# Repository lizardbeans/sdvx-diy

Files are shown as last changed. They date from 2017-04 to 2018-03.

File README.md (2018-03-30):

# SDVX Controller (DIY)

<div style='float: center'>
  
</div>

<hr>

Check [consandstuff.github.io/sound-voltex](http://consandstuff.github.io/rhythmcons/sound-voltex/sdvx-normal/) for full instructions.

CODE INSTRUCTIONS:

* Download and install ARDUINO IDE v1.8
https://www.arduino.cc/en/Main/OldSoftwareReleases#previous 

* Download and install Teensyduino
https://www.pjrc.com/teensy/td_download.html

* Add these lines to the C:\Program Files (x86)\Arduino\hardware\teensy\avr boards.txt file and save. 

teensy31.menu.usb.sdvx=SDVX controller

teensy31.menu.usb.sdvx.build.usbtype=USB_ARCADE

teensy31.menu.usb.sdvx.fake_serial=teensy_gateway

* Then add the 4 usb_arcade and usb_desc inside yout core/teensy3 folder and overwirte existing files.

*Alternatively download the whole set of folders and paste into Program Files.

* Open teensyduino and connect your PCB to the PC using a USB cable
* In Tools/USB Type choose SDVX Controller
* Open a blank Arduino IDE file (FIle - New) and click Verify to open the Teensyduino UI
* Hit the "Open HEX file" button and choose the file
* Click the hardware reset button on the Teensy PCB and it will upload.

Then you're done!

For the Leonardo CODE you'll need only Arduino IDE. Set the Arduino for a Leonardo and choose the right COM port.

<hr>

## Part List / Hardware

Check out the parts used on my website
You can find links here: http://consandstuff.github.io/rhythmcons/sound-voltex/sdvx-normal/

Skills needed:
* Wood cutting
* Soldering
* Drilling
* Sanding

## Part List / Building Materials

**Main box**
Made out of 5mm MDF planks. You have to make the box 3mm narrower on each side to mount the 3mm black acrylic.

**Side plates**
Made out of black 3mm acrylic. See CAD file.

**Top plate**
Made out of laser cut clear 5mm acrylic. See CAD file.

**Other**
20xM5 bolts, 4xM6 bolts, 4xmagnetic locks

<hr>

**PIN DIAGRAM (teensy only)**
<table><thead>
<tr>
<th>Button</th>
<th style="text-align: center">Pin #</th>
<th style="text-align: center">Button #</th>
<th style="text-align: center">LED Pin #</th>
</tr>
</thead><tbody>
<tr>
<td>Start</td>
<td style="text-align: center">4</td>
<td style="text-align: center">Button 1</td>
<td style="text-align: center">-</td>
</tr>
<tr>
<td>BT-A</td>
<td style="text-align: center">5</td>
<td style="text-align: center">Button 2</td>
<td style="text-align: center">-</td>
</tr>
<tr>
<td>FX-L</td>
<td style="text-align: center">6</td>
<td style="text-align: center">Button 3</td>
<td style="text-align: center">-</td>
</tr>
<tr>
<td>BT-B</td>
<td style="text-align: center">7</td>
<td style="text-align: center">Button 4</td>
<td style="text-align: center">-</td>
</tr>
<tr>
<td>BT-C</td>
<td style="text-align: center">8</td>
<td style="text-align: center">Button 5</td>
<td style="text-align: center">-</td>
</tr>
<tr>
<td>FX-R</td>
<td style="text-align: center">9</td>
<td style="text-align: center">Button 6</td>
<td style="text-align: center">-</td>
</tr>
<tr>
<td>BT-D</td>
<td style="text-align: center">10</td>
<td style="text-align: center">Button 7</td>
<td style="text-align: center">-</td>
</tr>
</tbody></table>

<table><thead>
<tr>
<th>ENCODERS</th>
<th style="text-align: center">DATA 1</th>
<th style="text-align: center">DATA 2</th>
</tr>
</thead><tbody>
<tr>
<td>Left knob (VOL-L)
<td style="text-align: center">0</td>
<td style="text-align: center">1</td>
</tr>
<tr>
<td>Right knob (VOL-R)
<td style="text-align: center">2</td>
<td style="text-align: center">3</td>
</tr>
</tbody></table>

**Also you have to connect the encoders to the VUSB pin to get the 5v input**

<hr>

**PIN LAYOUT (LEONARDO ARDUINO)**

<table><thead>
<tr>
<th>Button</th>
<th style="text-align: center">Pin #</th>
<th style="text-align: center">Button #</th>
<th style="text-align: center">LED Pin #</th>
</tr>
</thead><tbody>
<tr>
<td>Start</td>
<td style="text-align: center">13</td>
<td style="text-align: center">Button 1</td>
<td style="text-align: center">6</td>
</tr>
<tr>
<td>BT-A</td>
<td style="text-align: center">A0</td>
<td style="text-align: center">Button 2</td>
<td style="text-align: center">7</td>
</tr>
<tr>
<td>FX-L</td>
<td style="text-align: center">A1</td>
<td style="text-align: center">Button 3</td>
<td style="text-align: center">8</td>
</tr>
<tr>
<td>BT-B</td>
<td style="text-align: center">A2</td>
<td style="text-align: center">Button 4</td>
<td style="text-align: center">9</td>
</tr>
<tr>
<td>BT-C</td>
<td style="text-align: center">A3</td>
<td style="text-align: center">Button 5</td>
<td style="text-align: center">10</td>
</tr>
<tr>
<td>FX-R</td>
<td style="text-align: center">A4</td>
<td style="text-align: center">Button 6</td>
<td style="text-align: center">11</td>
</tr>
<tr>
<td>BT-D</td>
<td style="text-align: center">A5</td>
<td style="text-align: center">Button 7</td>
<td style="text-align: center">12</td>
</tr>
</tbody></table>

<table><thead>
<tr>
<th>ENCODERS</th>
<th style="text-align: center">DATA 1</th>
<th style="text-align: center">DATA 2</th>
</tr>
</thead><tbody>
<tr>
<td>Left knob (VOL-L)
<td style="text-align: center">0</td>
<td style="text-align: center">1</td>
</tr>
<tr>
<td>Right knob (VOL-R)
<td style="text-align: center">2</td>
<td style="text-align: center">3</td>
</tr>
</tbody></table>

>**Also you have to connect the encoders to the 5V pin for the 5v input**

<hr>

## Assembly / Building the controller

**Buttons**
Assembly every button in its place on the acrylic board. Use the plastic nut to keep them in place.
After that put the white plastic center in the button inserting it rotates 15° pushing and then locking it rotating it 15° back.
Don't forget to add your printed vynil bellow the clear acrylic before inserting the buttons.

**Encoders**
Mount the encoders using 3 small screws.

**Crimp Connectors**
Use crimp connectors in each wire of the 7 molex wires your gonna use. You should en up with 7 wires, each with 4 crimp connectors (1 LED, 1 DATA and 2 GROUND), and also 2 other wires for the encoders (1 DATA A, 1 DATA B, 1 5v input and 1 GROUND). 

**Perfboard**
Following this drawing (drawing pending) solder each male molex connector in the perfboard. Then using PCB wires solder each molex pin with another molex pin (For the DATA and LED pins) and solder all the grounds in a single line.

**Teensy**
Solder each corresponding molex wire to each hole in the PCB. You should end up with 3 6-pin wires.

Mount everything toghether connecting each molex wire to the perfboard and to the buttons.

>If a button doesn't work, try checking the solder to see if its connected properly. Also check the ground connections.

<hr>

## Gallery

[Step by step gallery](http://imgur.com/a/uVgB2)

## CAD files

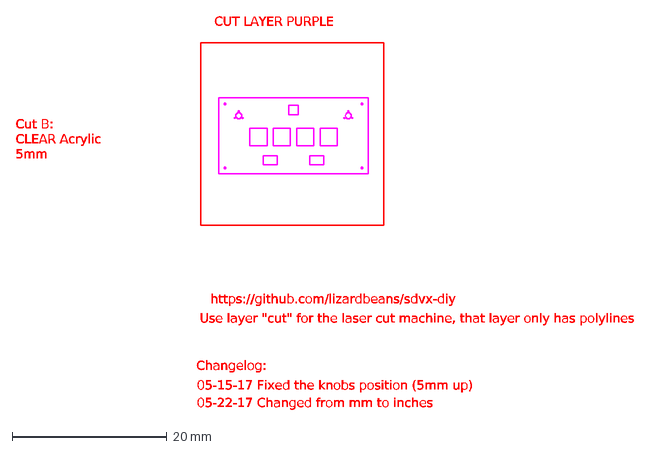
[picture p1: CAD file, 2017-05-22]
cad/Main Plate [inches] (AutoCAD 2010).dxf
Cut B:
CLEAR Acrylic
5mm
CUT LAYER PURPLE
https://github.com/lizardbeans/sdvx-diy
Use layer "cut" for the laser cut machine, that layer only has polylines
05-15-17 Fixed the knobs position (5mm up)
Changelog:
05-22-17 Changed from mm to inches

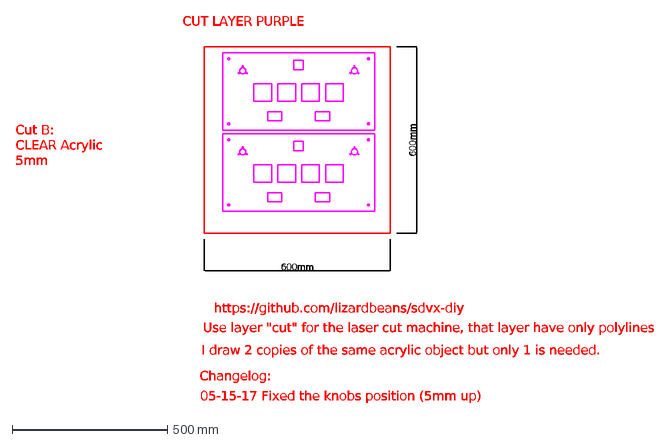
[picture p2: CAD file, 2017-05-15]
cad/Main Plate 600x600x5mm.dxf
Cut B:
CLEAR Acrylic
5mm
CUT LAYER PURPLE
600mm
https://github.com/lizardbeans/sdvx-diy
Use layer "cut" for the laser cut machine, that layer have only polylines
I draw 2 copies of the same acrylic object but only 1 is needed.
05-15-17 Fixed the knobs position (5mm up)
Changelog:

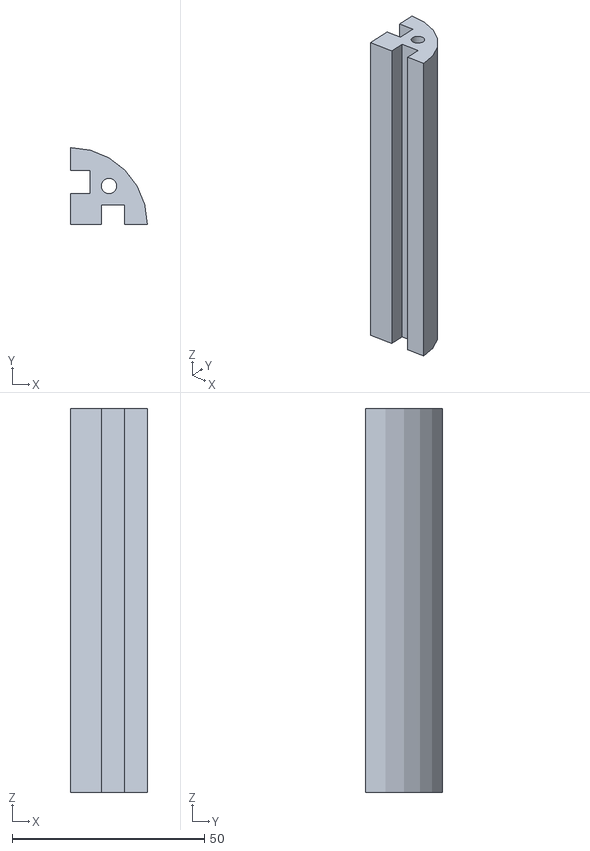
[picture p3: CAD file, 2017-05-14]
code Leonardo/skp/edge.stl
20.0 x 20.0 x 100.0

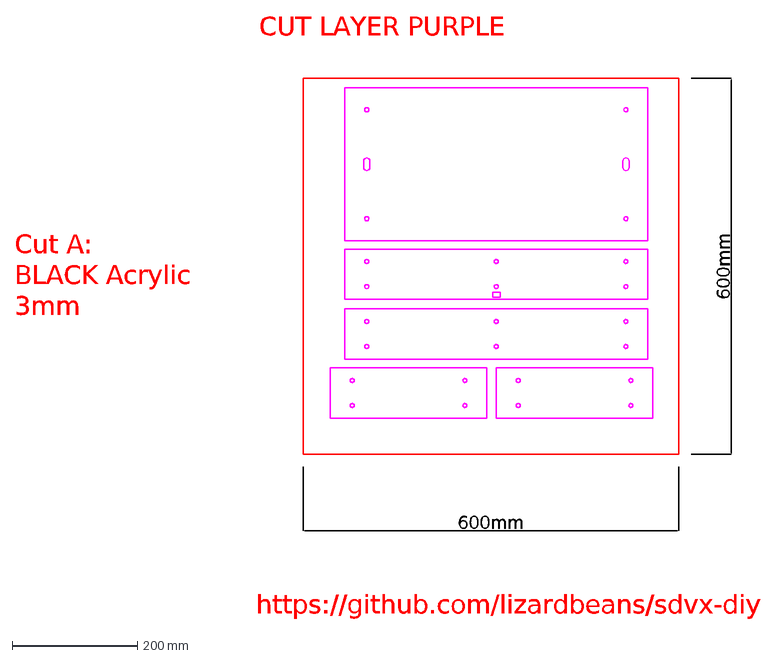
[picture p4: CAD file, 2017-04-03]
cad/Body 600x600x3mm.dxf
Cut A:
BLACK Acrylic
3mm
CUT LAYER PURPLE
600mm
https://github.com/lizardbeans/sdvx-diy

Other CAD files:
cad/Main Plate 600x600x5mm (AutoCAD 2010).dwg
cad/Main Plate 600x600x5mm (AutoCAD 2013).dwg
cad/Body 600x600x3mm (AutoCAD 2013).dwg
cad/Body 600x600x3mm (AutoCAD 2010).dwg
cad/Main Plate [inches] (AutoCAD 2010).dwg
code Leonardo/skp/edge.skp

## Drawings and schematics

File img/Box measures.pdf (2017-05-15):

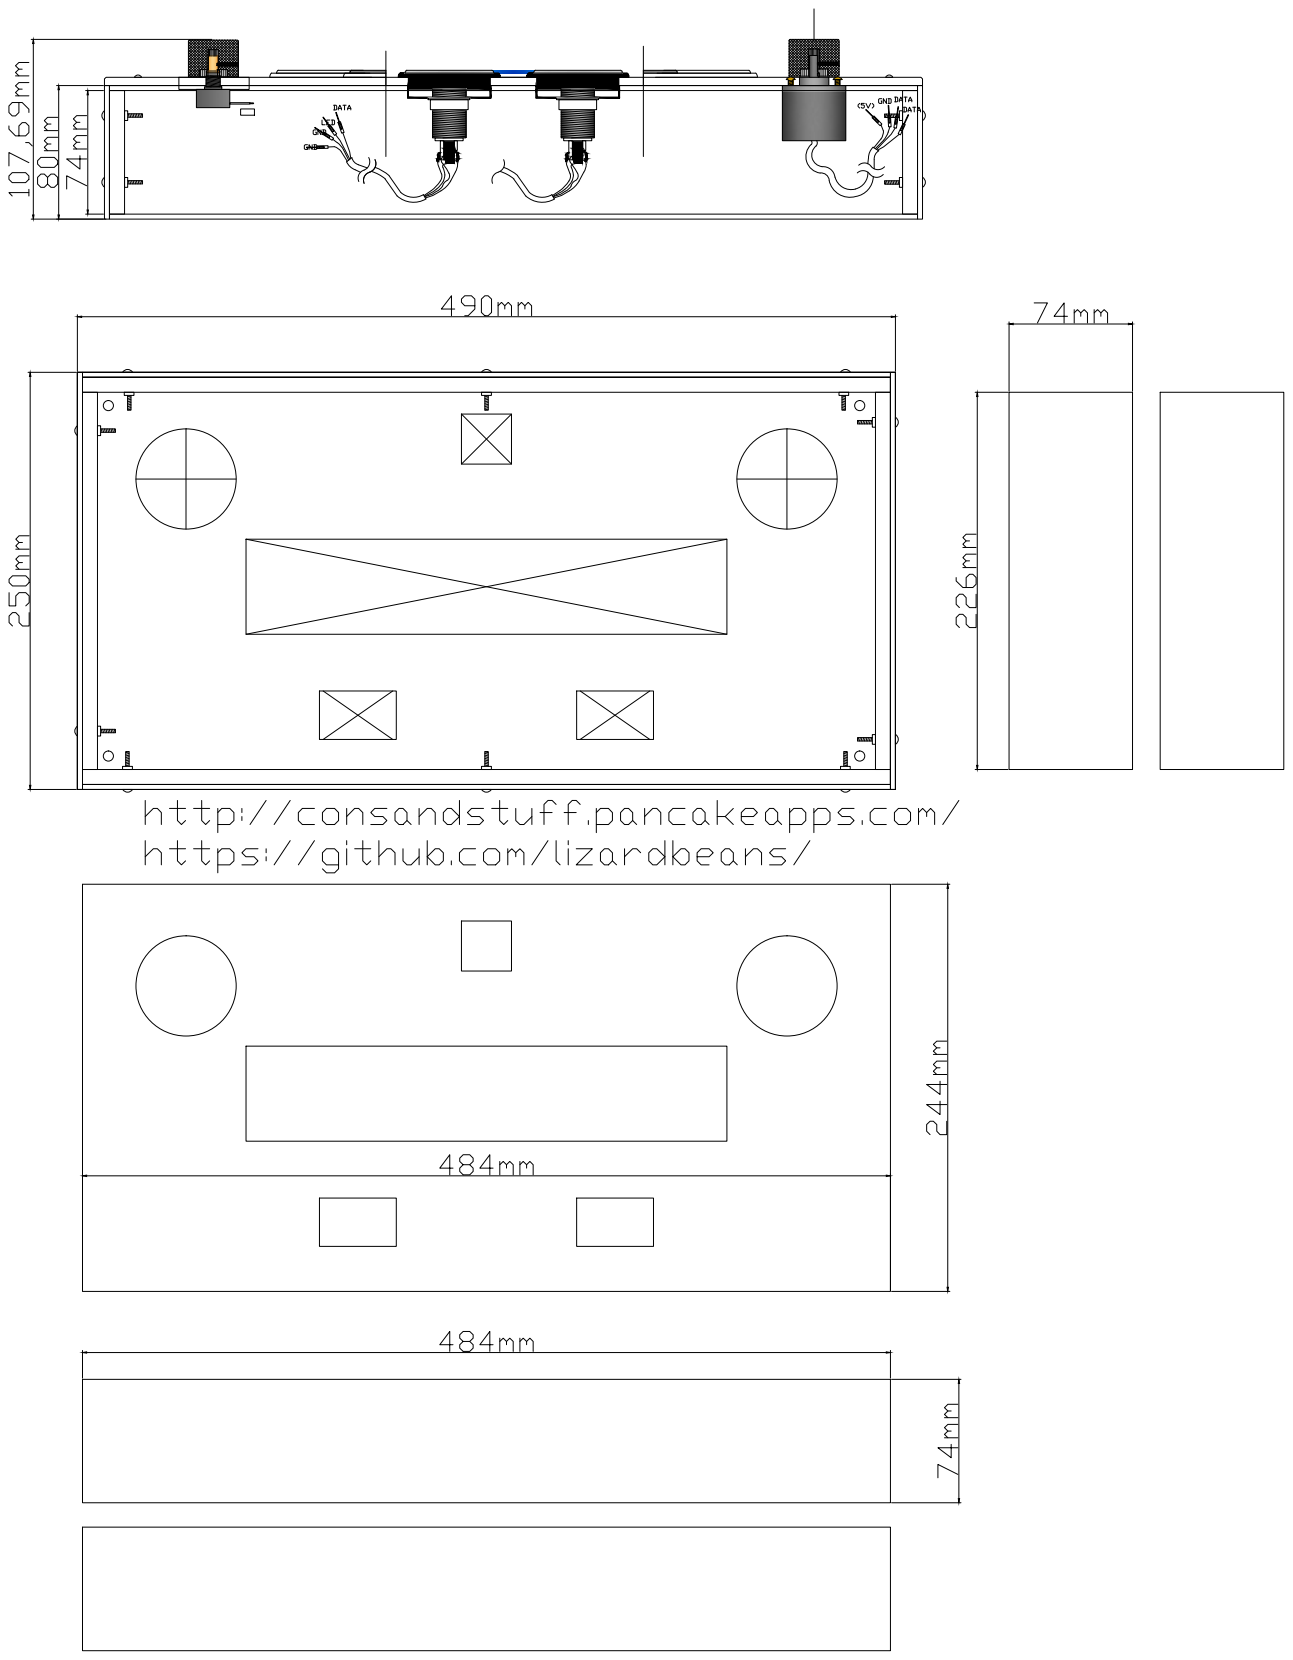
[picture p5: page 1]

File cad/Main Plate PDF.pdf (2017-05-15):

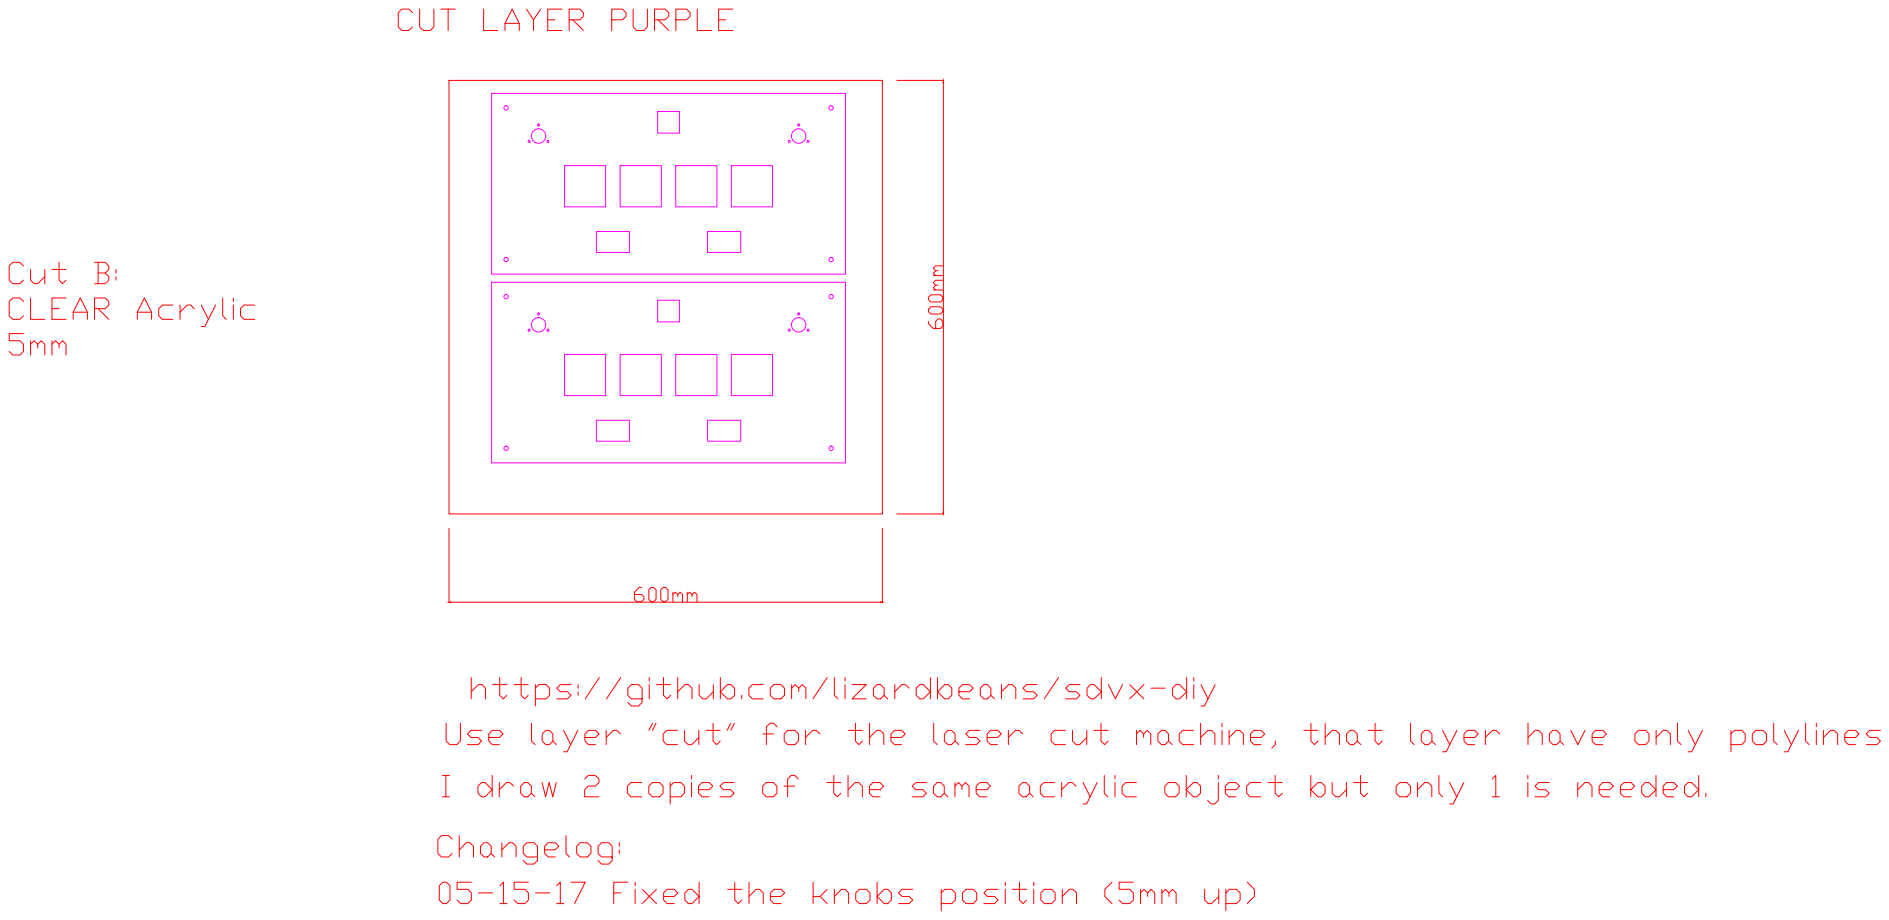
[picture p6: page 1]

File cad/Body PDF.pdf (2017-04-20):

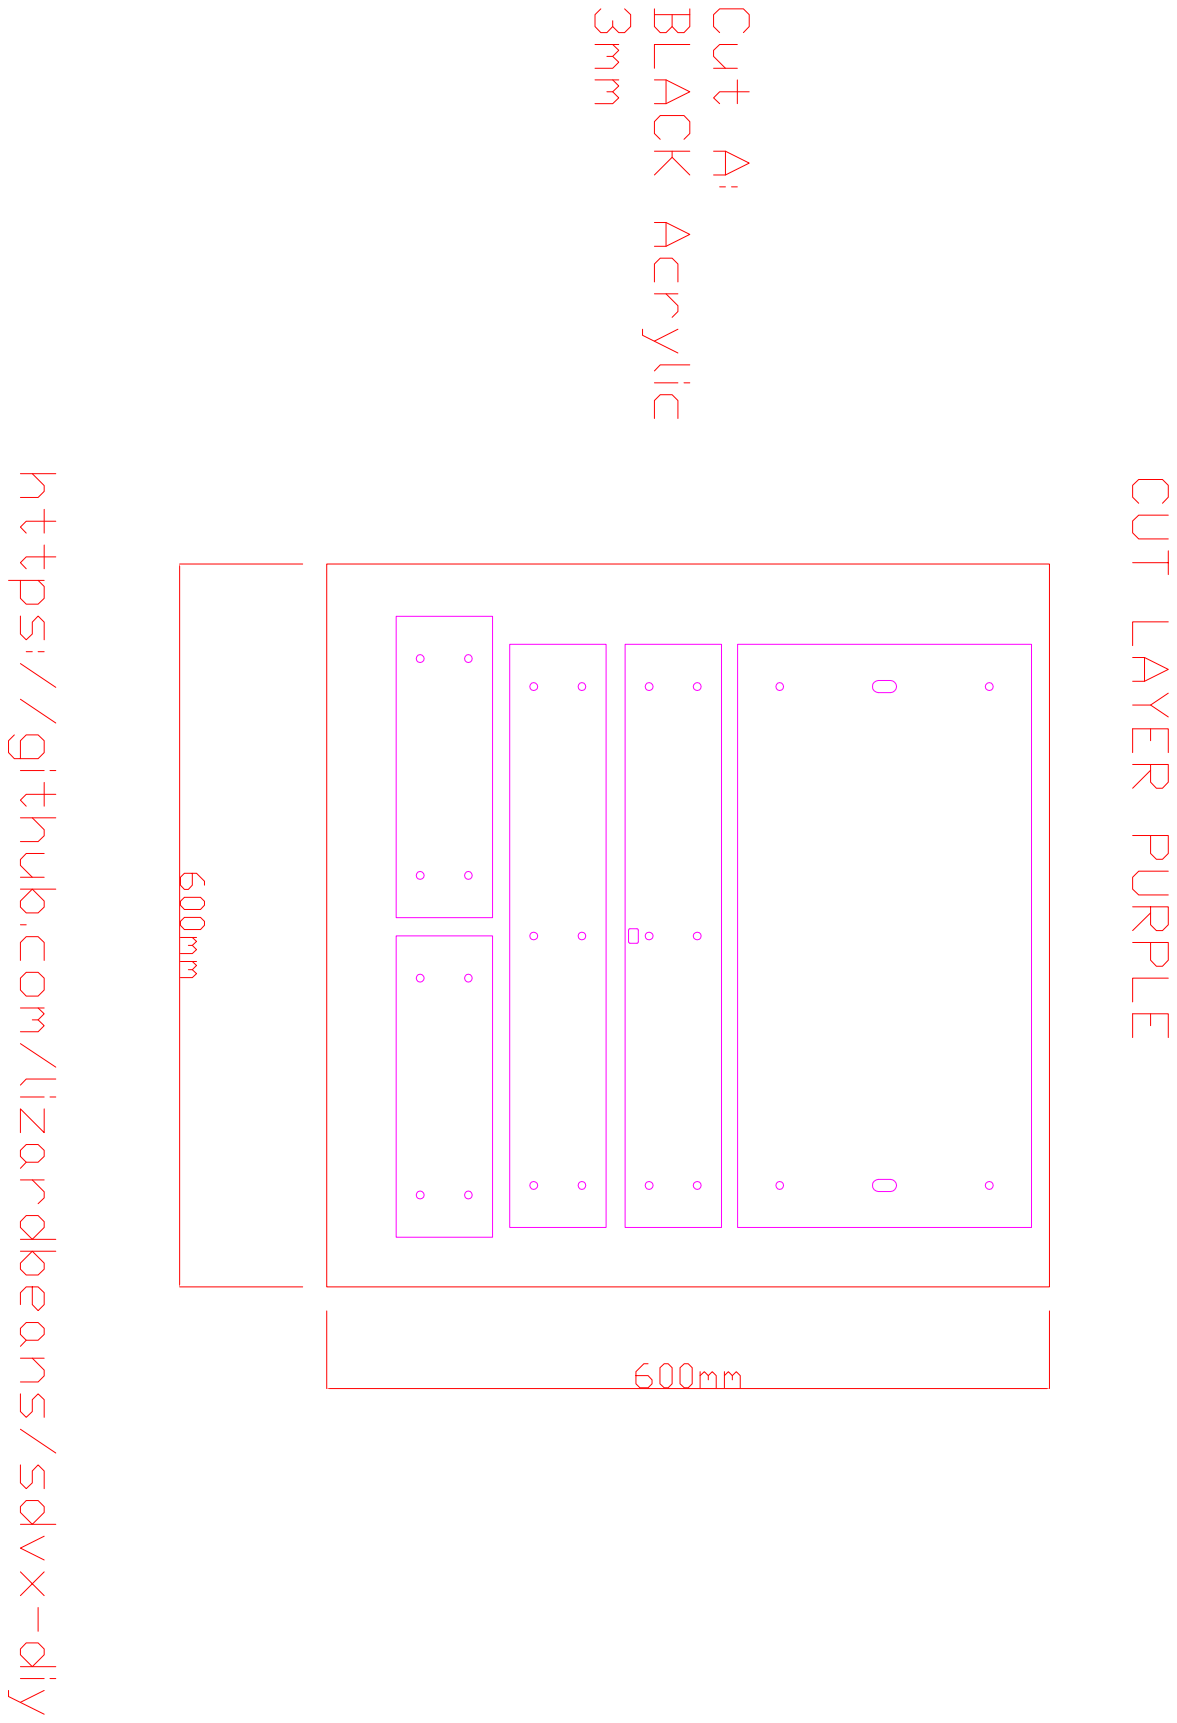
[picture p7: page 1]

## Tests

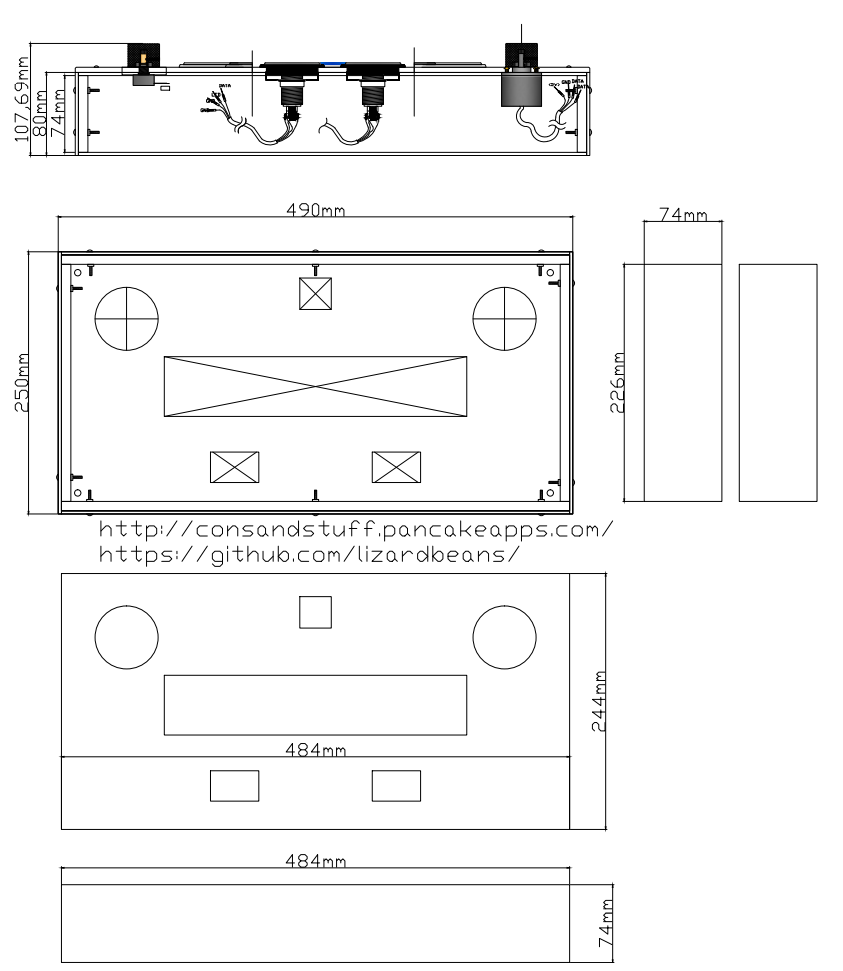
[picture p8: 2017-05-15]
img/Box Measures.png

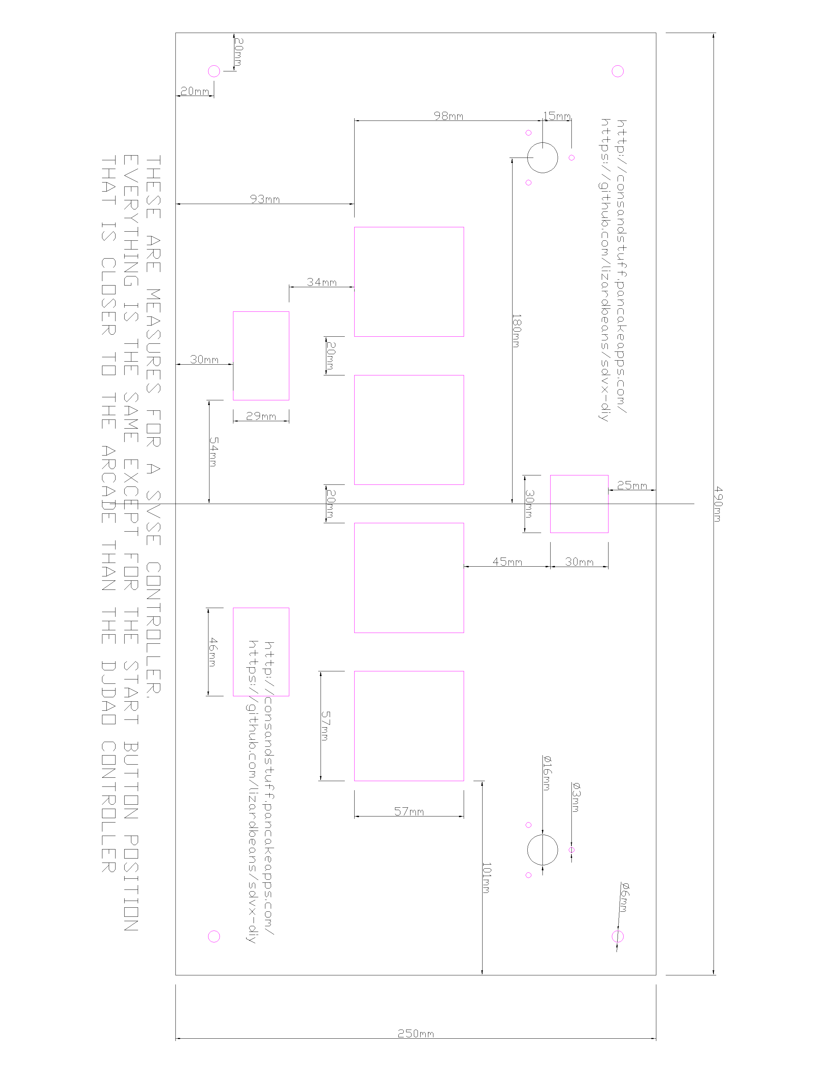
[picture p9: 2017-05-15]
img/SDVX measures.png

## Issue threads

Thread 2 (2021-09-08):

Encoders not working

MichaelOdet, 2021-09-08:
Hi,
Encoders not working. I use Arduino Leonardo.
When I test encoder with Windows Gaming Controller settings, buttons are OK. But nothing happen with encoders.

Just when I plug/unplug the +5V of left encoder, the X/Y axis increment of +1

Best regards.

michaelbutler, 2023-07-14:
@Mik027 did you ever figure it out?

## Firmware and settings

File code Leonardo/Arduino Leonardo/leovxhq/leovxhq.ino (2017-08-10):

#include "iivx_leo.h"
iivxReport_t report; 

#define REPORT_DELAY 2000
// Number of microseconds between HID reports
// 2000 = 500hz

#define ENC_L_A 0
#define ENC_L_B 1
#define ENC_L_B_ADDR 3
#define ENC_R_A 2
#define ENC_R_B 3
#define ENC_R_B_ADDR 0
#define ENCODER_SENSITIVITY (double) 2.34375
#define ENCODER_PORT PIND
// encoder sensitivity = number of positions per rotation (600/256) / number of positions for HID report (256)
/*
 * connect encoders
 * VOL-L to pins 0 and 1
 * VOL-R to pins 2 and 3
 */

int tmp;
uint8_t buttonCount = 7;
uint8_t lightMode = 0;
// 0 = reactive lighting, 1 = HID lighting
uint8_t ledPins[] = {6,7,8,9,10,11,12};
uint8_t buttonPins[] = {13,18,19,20,21,22,23};
uint8_t sysPin = 5;
uint8_t reactiveLightPin = 21;
uint8_t hidLightPin = 22;
uint8_t sysInputPins[] = {13,18,19,20};
int32_t encL=0, encR=0;
/* current pin layout
 *  pins 6 to 12 = LED 1 to 7
 *    connect pin to + termnial of LED
 *    connect ground to resistor and then - terminal of LED
 *  pins 13, A0 to A5 = Button input 1 to 7
 *    connect button pin to ground to trigger button press
 *  pins 5 = system pin
 *    connect system pin to ground with a small button
 *      press together with other buttons to change lighting scheme
 *    system button + button 1 = reactive lighting
 *    system button + button 3 = HID lighting
 */
 

void doEncL(){
  if((ENCODER_PORT >> ENC_L_B_ADDR)&1){
    encL++;
  } else {
    encL--;
  }
}

void doEncR(){
  if((ENCODER_PORT >> ENC_R_B_ADDR)&1){
    encR++;
  } else {
    encR--;
  }
}

void lights(uint8_t lightDesc){
  for(int i=0;i<buttonCount;i++){
     if((lightDesc>>i)&1){
         digitalWrite(ledPins[i],HIGH);
     } else {
         digitalWrite(ledPins[i],LOW);
     }
  }
}

void setup() {
  delay(1000);
  // Setup I/O for pins
  for(int i=0;i<buttonCount;i++){
    pinMode(buttonPins[i],INPUT_PULLUP);
    pinMode(ledPins[i],OUTPUT);
  }
  pinMode(sysPin,INPUT_PULLUP);
  //setup interrupts
  pinMode(ENC_L_A,INPUT_PULLUP);
  pinMode(ENC_L_B,INPUT_PULLUP);
  pinMode(ENC_R_A,INPUT_PULLUP);
  pinMode(ENC_R_B,INPUT_PULLUP);
  attachInterrupt(digitalPinToInterrupt(ENC_L_A), doEncL, RISING);
  attachInterrupt(digitalPinToInterrupt(ENC_R_A), doEncR, RISING);
}

void loop() {
  // Read buttons
  for(int i=0;i<buttonCount;i++){
    if(digitalRead(buttonPins[i])!=HIGH){
      report.buttons |= (uint16_t)1 << i;
    } else {
      report.buttons &= ~((uint16_t)1 << i);
    }
  }
  // Read Encoders
  report.xAxis = (uint8_t)((int32_t)(encL / ENCODER_SENSITIVITY) % 256);
  report.yAxis = (uint8_t)((int32_t)(encR / ENCODER_SENSITIVITY) % 256);
  // Light LEDs
  if(lightMode==0){
    lights(report.buttons);
  } else {
    lights(iivx_led);
  }
  // Detect Syspin Entries
  if(digitalRead(sysPin)!=HIGH){
    report.buttons = 0;
    for(int i=0;i<4;i++){
      if(digitalRead(sysInputPins[i])!=HIGH){
        report.buttons |= (uint16_t)1 << (i+buttonCount);
      } else {
        report.buttons &= ~((uint16_t)1 << (i+buttonCount));
      }
    }
    if(digitalRead(reactiveLightPin)!=HIGH){
      lightMode = 0;
    } else if (digitalRead(hidLightPin)!=HIGH){
      lightMode = 1;
    }
  }
  // Send report and delay
  iivx.setState(&report);
  delayMicroseconds(REPORT_DELAY);
}

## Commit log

2017-03-12 Initial hex code to upload directly to the PCB
2017-04-03 Added CAD files
    Use these for the acrylic machining.
    Notes:
    - Knobs position might mi lower than a DJ DAO SDSE
    - Encoder holes might need extra machining
    [Body 600x600x3mm.dxf, Main Plate 600x600x5mm.dxf]
2017-04-20 Added .dwg files in case dxf files are not working
    [Body 600x600x3mm.dwg, Main Plate 600x600x5mm.dwg]
2017-04-20 Added 2013 version of the file
    In case someone has compatibility issues with newer versions of AutoCAD
    [Body 600x600x3mm (AutoCAD 2010).dwg, Body 600x600x3mm (AutoCAD 2013).dwg, Main Plate 600x600x5mm (AutoCAD 2010).dwg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]
2017-04-20 Added CAD 2013 files
    [Body 600x600x3mm (AutoCAD 2010).dwg, Body 600x600x3mm (AutoCAD 2013).dwg, Main Plate 600x600x5mm (AutoCAD 2010).dwg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]
2017-04-20 old file
    [Body 600x600x3mm.dwg]
2017-05-14 Added code for Arduino Leonardo
    This is a modified version of this github https://github.com/4yn/iivx
    PLease direct any issues or thanks to that github.
    [edge.skp, edge.stl]
2017-05-15 Added measures in a PNG format
    These files have the knobs position fixed.
    CAD files are not yet updated as of 15/05/17
2017-05-15 Fixed knob position
    Now it should be a lot closer to the arcade.
    Also now skins from DJDAO's controller should fit, except for the start button.
    [Main Plate 600x600x5mm (AutoCAD 2010).dwg, Main Plate 600x600x5mm (AutoCAD 2013).dwg, Main Plate 600x600x5mm.dxf]
2017-05-22 Added CAD file in INCHES
    Main plate scaled to from mm to inches.
    [Main Plate [inches] (AutoCAD 2010).dwg, Main Plate [inches] (AutoCAD 2010).dxf]
2017-06-16 Added boards.txt to add USB Type
2017-06-17 Update file
    Fixed encoders not working.
2017-08-29 Update leovx.ino
    Changed code to inlcude both encoders.
2017-09-08 Fixed Leonardo pin layout
2017-09-08 Fix led pin order to match the table.
    [leovx.ino]
